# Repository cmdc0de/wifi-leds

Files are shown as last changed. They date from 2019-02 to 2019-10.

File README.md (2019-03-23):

# wifi-leds
wifi controlled LEDs

Goal of project:
* Build a web server on esp 32
* use a n-type mosfet to control power to an APA 102c LED strip
* use a ATECC608a for crypto and random number generator. you ask why? I say why not?
* add 2 displays 1. 2.4 SPI touch screen and 1 OLED I2C 
  * Again you ask why? mostly becuase I'm also working on the darknet 8 badge and one of these will be on that badge and it'll help me prepare.
* Pull out JTAG pins so I can try to debug from container.  Harder than it sounds becuase you need to run the open ocd server

Secondary Goals:
* Make the traces as thick as possible, so I can try to not only mill the board with my Bantam but also use 'print' the board using the Voltera.

Code:
* On linux:
* run buildESPContainer.sh
* ./runESPContainer.sh
* cd into firmware directory
* make menuconfig - set up usb port your usb to serial programmer is registered as
* make flash - build and push to dev board
* make monitor 
*

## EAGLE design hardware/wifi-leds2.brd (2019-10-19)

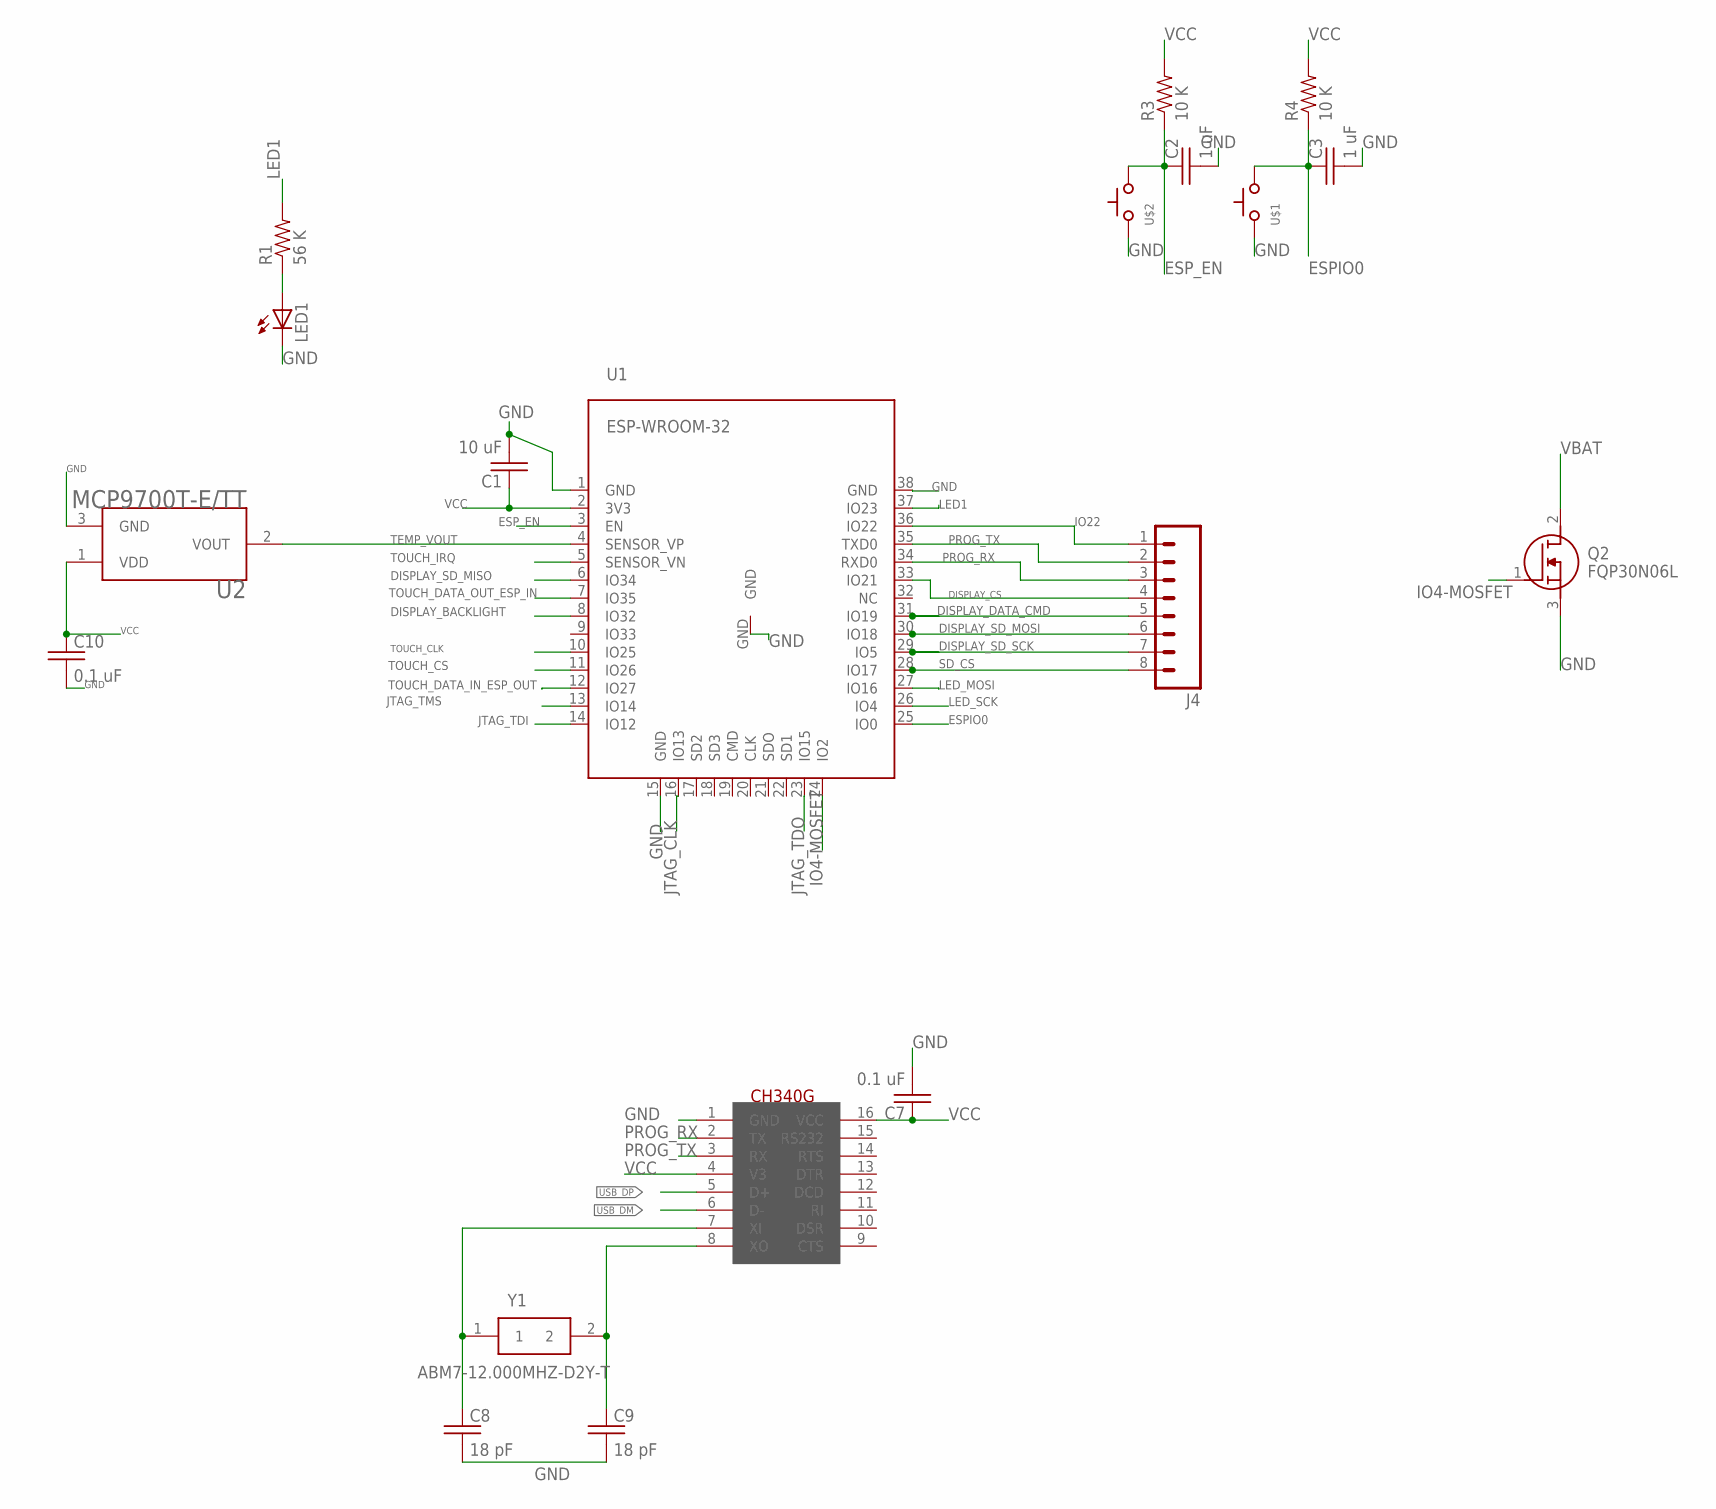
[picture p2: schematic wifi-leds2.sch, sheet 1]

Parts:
C1: 10 uF; C0805
C2, C3: 1 uF; C0805
C7, C10: 0.1 uF; C0805
C8, C9: 18 pF; C0805
J4: M08; 1X08_ROUND
LED1: LED3MM
Q2: FQP30N06L; TO254P470X1016X2019-3P
R1: 56 K; 0805
R3, R4: 10 K; 0805
U1: ESP-WROOM-32
U2: MCP9700T-E/TT; SOT95P237X112-3N
U$1, U$2: SWITCH_TACTILETACTILE-2PIN-NARROW; TACTILE-2PIN-NARROW
U$6: CH340G; SOIC16
Y1: ABM7-12.000MHZ-D2Y-T; ABM7

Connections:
DISPLAY_BACKLIGHT: U1.8 (IO32); also elsewhere on the board
DISPLAY_CS: J4.4, U1.33 (IO21); also elsewhere on the board
DISPLAY_DATA_CMD: J4.5, U1.31 (IO19); also elsewhere on the board
DISPLAY_SD_MISO: U1.6 (IO34); also elsewhere on the board
DISPLAY_SD_MOSI: J4.6, U1.30 (IO18); also elsewhere on the board
DISPLAY_SD_SCK: J4.7, U1.29 (IO5); also elsewhere on the board
ESPIO0: C3.1, R4.1, U1.25 (IO0), U$1.P$1 (A)
ESP_EN: C2.1, R3.1, U1.3 (EN), U$2.P$1 (A)
GND: C1.2, C2.2, C3.2, C7.2, C8.2, C9.2, C10.2, LED1.K (C), Q2.3 (S), U1.1 (GND), U1.15 (GND), U1.38 (GND), U1.GND, U2.3 (GND), U$1.P$2 (C), U$2.P$2 (C), U$6.1 (GND); also elsewhere on the board
IO4-MOSFET: Q2.1 (G), U1.24 (IO2)
IO22: J4.1, U1.36 (IO22)
JTAG_CLK: U1.16 (IO13); also elsewhere on the board
JTAG_TDI: U1.14 (IO12); also elsewhere on the board
JTAG_TDO: U1.23 (IO15); also elsewhere on the board
JTAG_TMS: U1.13 (IO14); also elsewhere on the board
LED1: R1.2, U1.37 (IO23)
LED_MOSI: U1.27 (IO16); also elsewhere on the board
LED_SCK: U1.26 (IO4); also elsewhere on the board
unnamed: LED1.A, R1.1
unnamed: C8.1, U$6.7 (XI), Y1.1
unnamed: C9.1, U$6.8 (XO), Y1.2
PROG_RX: J4.3, U1.34 (RXD0), U$6.2 (TX); also elsewhere on the board
PROG_TX: J4.2, U1.35 (TXD0), U$6.3 (RX); also elsewhere on the board
SD_CS: J4.8, U1.28 (IO17); also elsewhere on the board
TEMP_VOUT: U1.4 (SENSOR_VP), U2.2 (VOUT)
TOUCH_CLK: U1.10 (IO25); also elsewhere on the board
TOUCH_CS: U1.11 (IO26); also elsewhere on the board
TOUCH_DATA_IN_ESP_OUT: U1.12 (IO27); also elsewhere on the board
TOUCH_DATA_OUT_ESP_IN: U1.7 (IO35); also elsewhere on the board
TOUCH_IRQ: U1.5 (SENSOR_VN); also elsewhere on the board
USB_DM: U$6.6 (D-); also elsewhere on the board
USB_DP: U$6.5 (D+); also elsewhere on the board
VBAT: Q2.2 (D); also elsewhere on the board
VCC: C1.1, C7.1, C10.1, R3.2, R4.2, U1.2 (3V3), U2.1 (VDD), U$6.4 (V3), U$6.16 (VCC); also elsewhere on the board

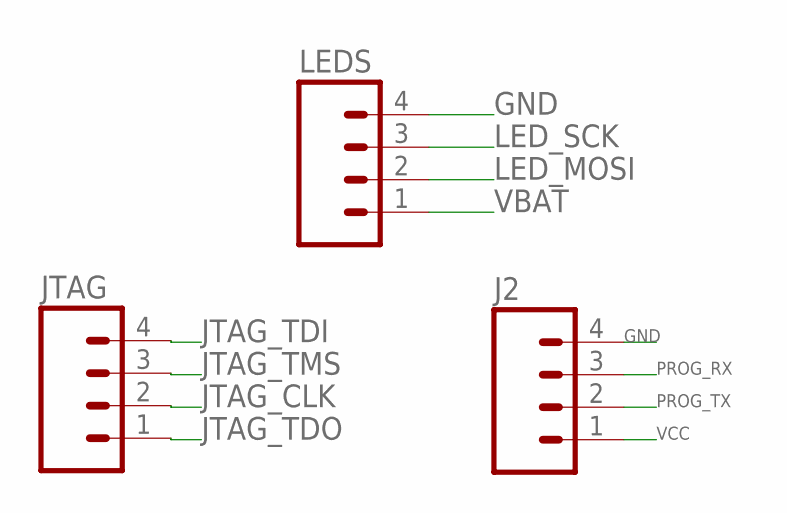
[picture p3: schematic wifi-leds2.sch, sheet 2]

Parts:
J2: M04PTH; 1X04
JTAG: M04PTH; 1X04
LEDS: M04POLAR; MOLEX-1X4

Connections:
GND: J2.4, LEDS.4; also elsewhere on the board
JTAG_CLK: JTAG.2; also elsewhere on the board
JTAG_TDI: JTAG.4; also elsewhere on the board
JTAG_TDO: JTAG.1; also elsewhere on the board
JTAG_TMS: JTAG.3; also elsewhere on the board
LED_MOSI: LEDS.2; also elsewhere on the board
LED_SCK: LEDS.3; also elsewhere on the board
PROG_RX: J2.3; also elsewhere on the board
PROG_TX: J2.2; also elsewhere on the board
VBAT: LEDS.1; also elsewhere on the board
VCC: J2.1; also elsewhere on the board

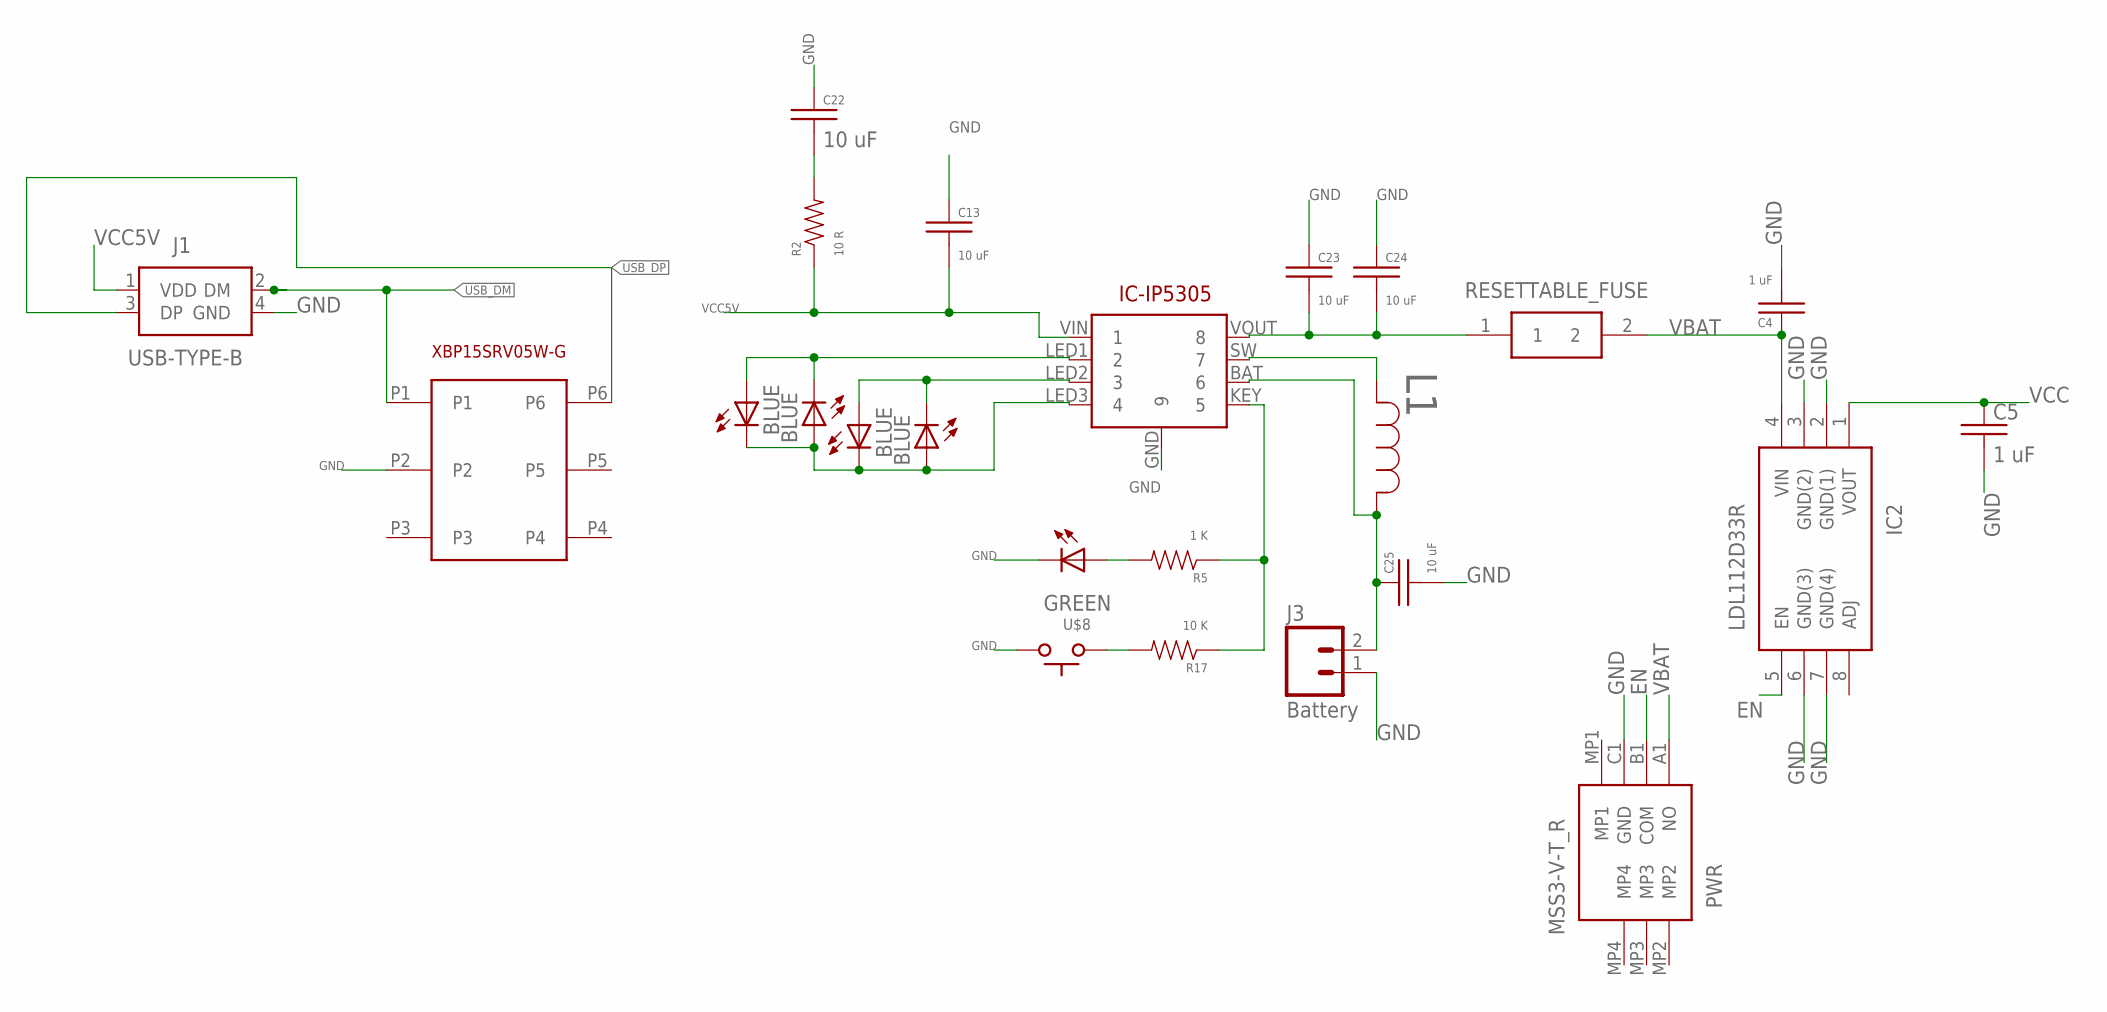
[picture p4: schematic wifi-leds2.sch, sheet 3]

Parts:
C4, C5: 1 uF; C0805
C13, C22, C23, C24, C25: 10 uF; C0805
CL1, CL2, CL3, CL4: BLUE; LED-1206
IC2: LDL112D33R; SOIC127P600X175-8N
IC-IP5305: IP5305ESOP8; SOIC127P600X165-8
J1: USB-TYPE-B; 61400413321
J3: Battery; JST-2-PTH
KEYLED: GREEN; LED-1206
L1: 2.2uH; IND_TAIYO_NRS4018
PWR: MSS3-V-T_R; MSS3VTR
R2: 10 R; 0805
R5: 1 K; 0805
R17: 10 K; 0805
RESETTABLE_FUSE: 0ZCJ0050FF2G; FUSC3216X55N
U$8: SWITCH_TACTILETACTILE-2PIN-NARROW; TACTILE-2PIN-NARROW
U$9: XBP15SRV05W-G; SOT-26P-XBP15SRV05W-G

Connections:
EN: IC2.5 (EN), PWR.B1 (COM)
GND: C4.2, C5.2, C13.1, C22.1, C23.1, C24.1, C25.2, IC2.2 (GND(1)), IC2.3 (GND(2)), IC2.6 (GND(3)), IC2.7 (GND(4)), IC-IP5305.GND (9), J1.4 (GND), J3.1, KEYLED.C, PWR.C1 (GND), U$8.P$1 (A), U$9.P2; also elsewhere on the board
unnamed: CL1.A, CL2.C, IC-IP5305.LED1 (2)
unnamed: CL3.A, CL4.C, IC-IP5305.LED2 (3)
unnamed: CL1.C, CL2.A, CL3.C, CL4.A, IC-IP5305.LED3 (4)
unnamed: C22.2, R2.2
unnamed: IC-IP5305.SW (7), L1.2
unnamed: C25.1, IC-IP5305.BAT (6), J3.2, L1.1
unnamed: IC-IP5305.KEY (5), R5.1, R17.1
unnamed: KEYLED.A, R5.2
unnamed: R17.2, U$8.P$2 (C)
unnamed: C23.2, C24.2, IC-IP5305.VOUT (8), RESETTABLE_FUSE.1
USB_DM: J1.2 (DM), U$9.P1; also elsewhere on the board
USB_DP: J1.3 (DP), U$9.P6; also elsewhere on the board
VBAT: C4.1, IC2.4 (VIN), PWR.A1 (NO), RESETTABLE_FUSE.2; also elsewhere on the board
VCC: C5.1, IC2.1 (VOUT); also elsewhere on the board
VCC5V: C13.2, IC-IP5305.VIN (1), J1.1 (VDD), R2.1

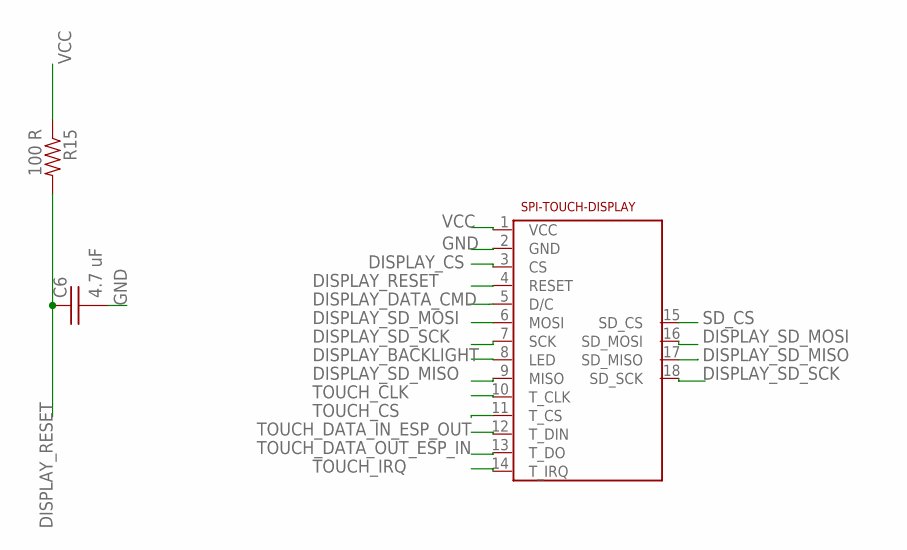
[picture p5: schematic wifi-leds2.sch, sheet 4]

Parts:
C6: 4.7 uF; C0805
R15: 100 R; 0805
U$3: 2.4-SPI-TFT-TOUCH-SSD-MODULE

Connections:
DISPLAY_BACKLIGHT: U$3.8 (LED); also elsewhere on the board
DISPLAY_CS: U$3.3 (CS); also elsewhere on the board
DISPLAY_DATA_CMD: U$3.5 (D/C); also elsewhere on the board
DISPLAY_RESET: C6.1, R15.2, U$3.4 (RESET)
DISPLAY_SD_MISO: U$3.9 (MISO), U$3.17 (SD_MISO); also elsewhere on the board
DISPLAY_SD_MOSI: U$3.6 (MOSI), U$3.16 (SD_MOSI); also elsewhere on the board
DISPLAY_SD_SCK: U$3.7 (SCK), U$3.18 (SD_SCK); also elsewhere on the board
GND: C6.2, U$3.2 (GND); also elsewhere on the board
SD_CS: U$3.15 (SD_CS); also elsewhere on the board
TOUCH_CLK: U$3.10 (T_CLK); also elsewhere on the board
TOUCH_CS: U$3.11 (T_CS); also elsewhere on the board
TOUCH_DATA_IN_ESP_OUT: U$3.12 (T_DIN); also elsewhere on the board
TOUCH_DATA_OUT_ESP_IN: U$3.13 (T_DO); also elsewhere on the board
TOUCH_IRQ: U$3.14 (T_IRQ); also elsewhere on the board
VCC: R15.1, U$3.1 (VCC); also elsewhere on the board

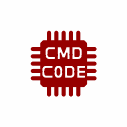
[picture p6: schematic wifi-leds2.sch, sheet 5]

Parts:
U$5: CMD_C0DE_LOGOCMD_CODE_LOGO_TOP_COPPER; CMD_C0DE_LOGO_TOP_COPPER

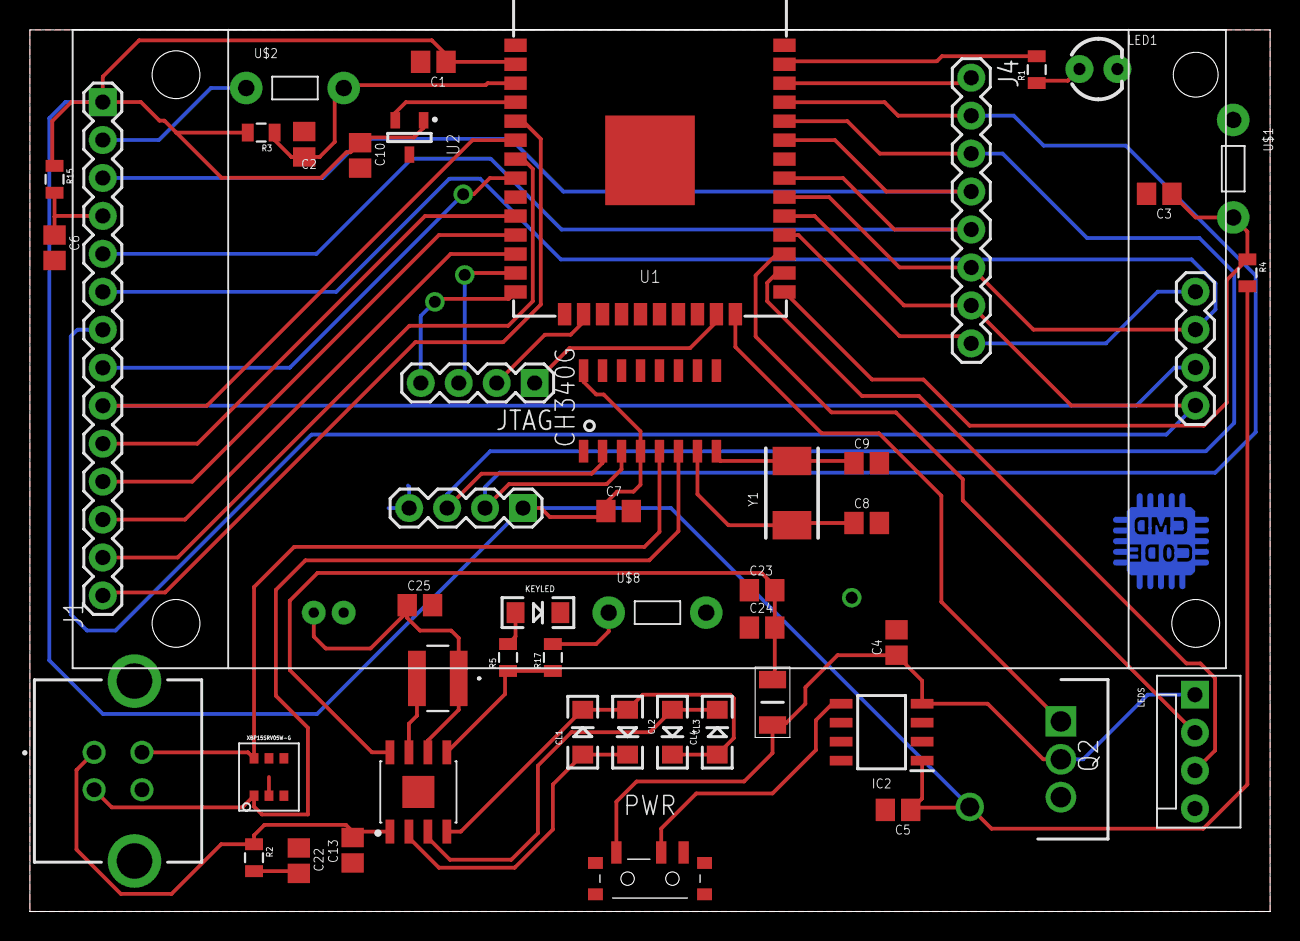
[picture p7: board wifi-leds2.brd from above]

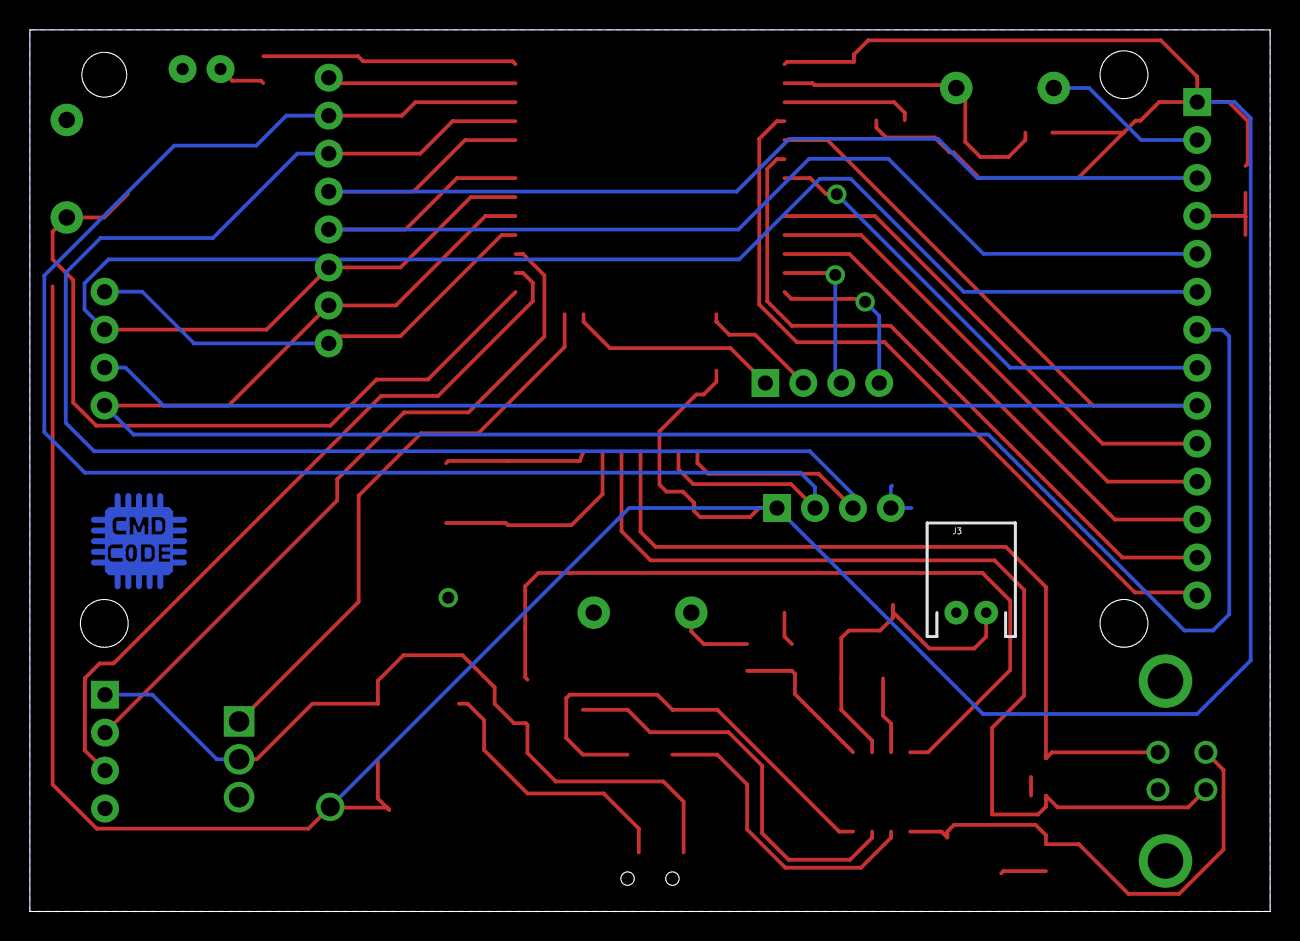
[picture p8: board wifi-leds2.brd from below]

Board: 2 copper layers, 83.0 x 59.0 mm, 50 parts (2 on the bottom side), 47 nets.

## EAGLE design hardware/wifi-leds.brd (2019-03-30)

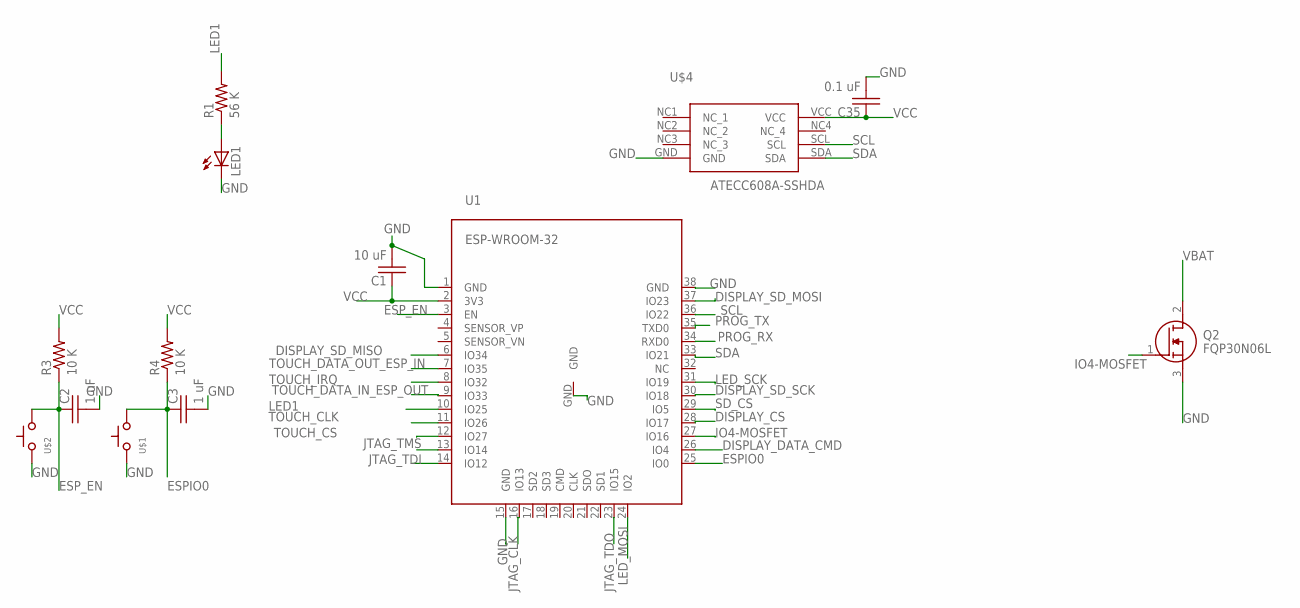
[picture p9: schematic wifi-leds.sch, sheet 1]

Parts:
C1: 10 uF; C0805
C2, C3: 1 uF; C0805
C35: 0.1 uF; C0805
LED1: LED3MM
Q2: FQP30N06L; TO254P470X1016X2019-3P
R1: 56 K; 0805
R3, R4: 10 K; 0805
U1: ESP-WROOM-32
U$1, U$2: SWITCH_TACTILETACTILE-2PIN-NARROW; TACTILE-2PIN-NARROW
U$4: ATECC608A-SSHDA; 8-SOIC

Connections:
DISPLAY_CS: U1.28 (IO17); also elsewhere on the board
DISPLAY_DATA_CMD: U1.26 (IO4); also elsewhere on the board
DISPLAY_SD_MISO: U1.6 (IO34); also elsewhere on the board
DISPLAY_SD_MOSI: U1.37 (IO23); also elsewhere on the board
DISPLAY_SD_SCK: U1.30 (IO18); also elsewhere on the board
ESPIO0: C3.1, R4.1, U1.25 (IO0), U$1.P$1 (A)
ESP_EN: C2.1, R3.1, U1.3 (EN), U$2.P$1 (A)
GND: C1.2, C2.2, C3.2, C35.2, LED1.K (C), Q2.3 (S), U1.1 (GND), U1.15 (GND), U1.38 (GND), U1.GND, U$1.P$2 (C), U$2.P$2 (C), U$4.GND; also elsewhere on the board
IO4-MOSFET: Q2.1 (G), U1.27 (IO16)
JTAG_CLK: U1.16 (IO13); also elsewhere on the board
JTAG_TDI: U1.14 (IO12); also elsewhere on the board
JTAG_TDO: U1.23 (IO15); also elsewhere on the board
JTAG_TMS: U1.13 (IO14); also elsewhere on the board
LED1: R1.2, U1.10 (IO25)
LED_MOSI: U1.24 (IO2); also elsewhere on the board
LED_SCK: U1.31 (IO19); also elsewhere on the board
unnamed: LED1.A, R1.1
PROG_RX: U1.34 (RXD0); also elsewhere on the board
PROG_TX: U1.35 (TXD0); also elsewhere on the board
SCL: U1.36 (IO22), U$4.SCL; also elsewhere on the board
SDA: U1.33 (IO21), U$4.SDA; also elsewhere on the board
SD_CS: U1.29 (IO5); also elsewhere on the board
TOUCH_CLK: U1.11 (IO26); also elsewhere on the board
TOUCH_CS: U1.12 (IO27); also elsewhere on the board
TOUCH_DATA_IN_ESP_OUT: U1.9 (IO33); also elsewhere on the board
TOUCH_DATA_OUT_ESP_IN: U1.7 (IO35); also elsewhere on the board
TOUCH_IRQ: U1.8 (IO32); also elsewhere on the board
VBAT: Q2.2 (D); also elsewhere on the board
VCC: C1.1, C35.1, R3.2, R4.2, U1.2 (3V3), U$4.VCC; also elsewhere on the board

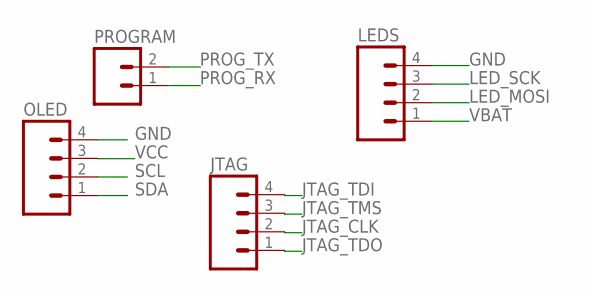
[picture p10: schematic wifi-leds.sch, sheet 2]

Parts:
JTAG: M04PTH; 1X04
LEDS: M04POLAR; MOLEX-1X4
OLED: M04PTH; 1X04
PROGRAM: M02PTH; 1X02

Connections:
GND: LEDS.4, OLED.4; also elsewhere on the board
JTAG_CLK: JTAG.2; also elsewhere on the board
JTAG_TDI: JTAG.4; also elsewhere on the board
JTAG_TDO: JTAG.1; also elsewhere on the board
JTAG_TMS: JTAG.3; also elsewhere on the board
LED_MOSI: LEDS.2; also elsewhere on the board
LED_SCK: LEDS.3; also elsewhere on the board
PROG_RX: PROGRAM.1; also elsewhere on the board
PROG_TX: PROGRAM.2; also elsewhere on the board
SCL: OLED.2; also elsewhere on the board
SDA: OLED.1; also elsewhere on the board
VBAT: LEDS.1; also elsewhere on the board
VCC: OLED.3; also elsewhere on the board

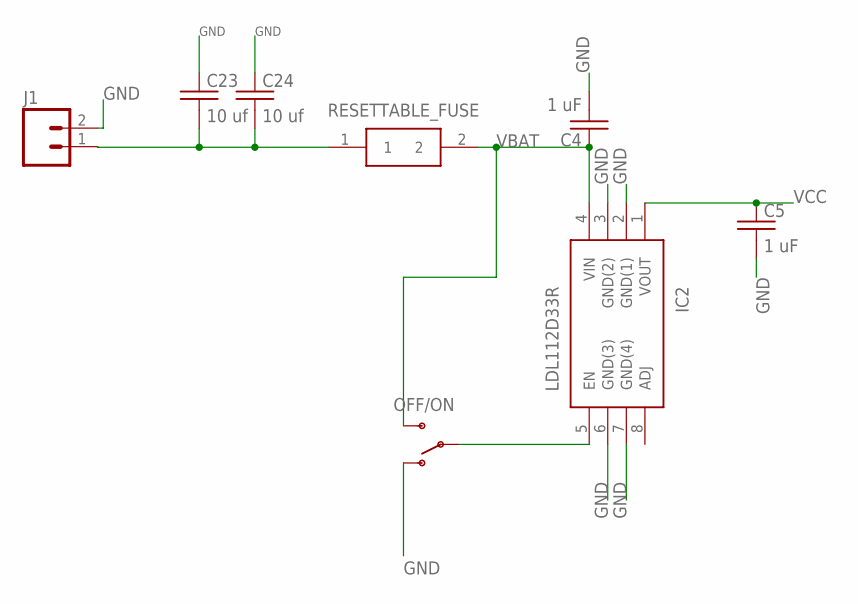
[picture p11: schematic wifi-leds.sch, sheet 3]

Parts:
C4, C5: 1 uF; C0805
C23, C24: 10 uf; C0805
IC2: LDL112D33R; SOIC127P600X175-8N
J1: M02PTH; 1X02
OFF/ON: SWITCH-SPSTKIT; SWITCH-SPDT_KIT
RESETTABLE_FUSE: 0ZCJ0050FF2G; FUSC3216X55N

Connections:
GND: C4.2, C5.2, C23.1, C24.1, IC2.2 (GND(1)), IC2.3 (GND(2)), IC2.6 (GND(3)), IC2.7 (GND(4)), J1.2, OFF/ON.1 (O); also elsewhere on the board
unnamed: IC2.5 (EN), OFF/ON.2
unnamed: C23.2, C24.2, J1.1, RESETTABLE_FUSE.1
VBAT: C4.1, IC2.4 (VIN), OFF/ON.3 (S), RESETTABLE_FUSE.2; also elsewhere on the board
VCC: C5.1, IC2.1 (VOUT); also elsewhere on the board

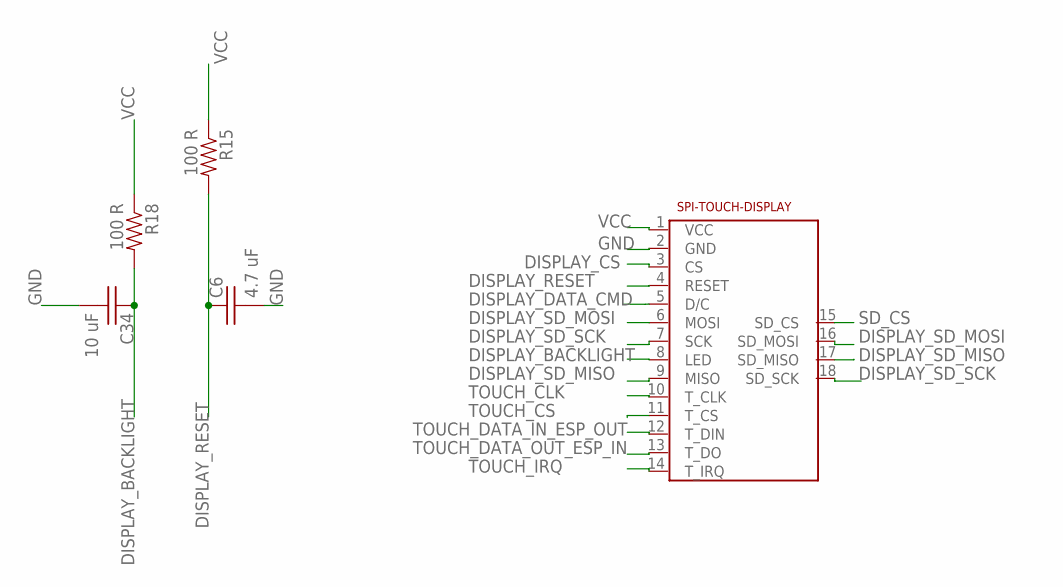
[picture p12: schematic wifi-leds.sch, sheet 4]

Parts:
C6: 4.7 uF; C0805
C34: 10 uF; C0805
R15, R18: 100 R; 0805
U$3: 2.4-SPI-TFT-TOUCH-SSD-MODULE

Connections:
DISPLAY_BACKLIGHT: C34.1, R18.2, U$3.8 (LED)
DISPLAY_CS: U$3.3 (CS); also elsewhere on the board
DISPLAY_DATA_CMD: U$3.5 (D/C); also elsewhere on the board
DISPLAY_RESET: C6.1, R15.2, U$3.4 (RESET)
DISPLAY_SD_MISO: U$3.9 (MISO), U$3.17 (SD_MISO); also elsewhere on the board
DISPLAY_SD_MOSI: U$3.6 (MOSI), U$3.16 (SD_MOSI); also elsewhere on the board
DISPLAY_SD_SCK: U$3.7 (SCK), U$3.18 (SD_SCK); also elsewhere on the board
GND: C6.2, C34.2, U$3.2 (GND); also elsewhere on the board
SD_CS: U$3.15 (SD_CS); also elsewhere on the board
TOUCH_CLK: U$3.10 (T_CLK); also elsewhere on the board
TOUCH_CS: U$3.11 (T_CS); also elsewhere on the board
TOUCH_DATA_IN_ESP_OUT: U$3.12 (T_DIN); also elsewhere on the board
TOUCH_DATA_OUT_ESP_IN: U$3.13 (T_DO); also elsewhere on the board
TOUCH_IRQ: U$3.14 (T_IRQ); also elsewhere on the board
VCC: R15.1, R18.1, U$3.1 (VCC); also elsewhere on the board


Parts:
U$5: CMD_C0DE_LOGOCMD_CODE_LOGO_TOP_COPPER; CMD_C0DE_LOGO_TOP_COPPER

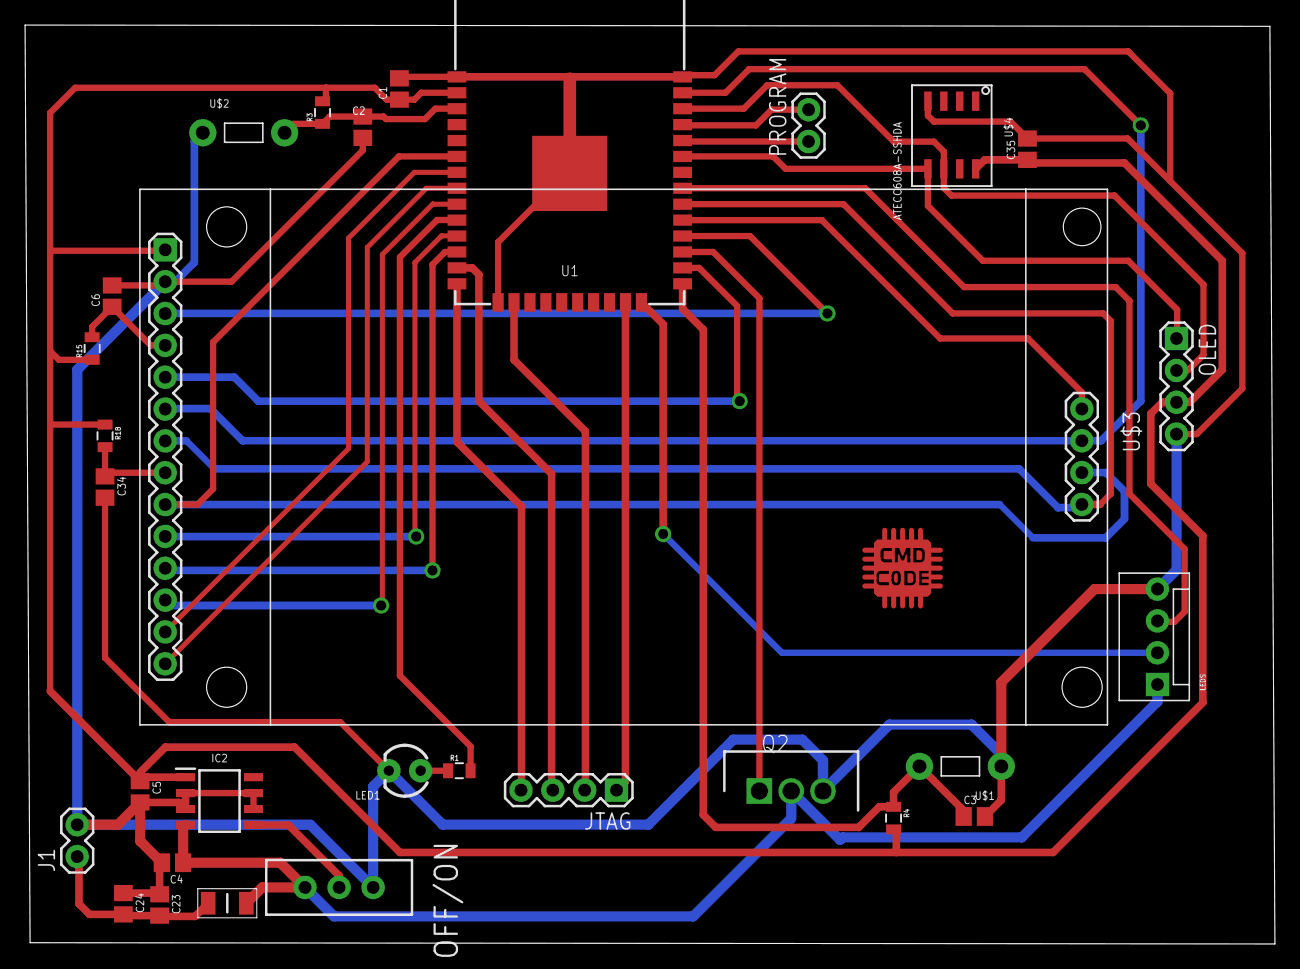
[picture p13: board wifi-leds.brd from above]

Board: 2 copper layers, 99.7 x 73.3 mm, 31 parts (0 on the bottom side), 33 nets.

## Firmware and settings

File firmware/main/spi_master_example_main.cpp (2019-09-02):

/* SPI Master example

   This example code is in the Public Domain (or CC0 licensed, at your option.)

   Unless required by applicable law or agreed to in writing, this
   software is distributed on an "AS IS" BASIS, WITHOUT WARRANTIES OR
   CONDITIONS OF ANY KIND, either express or implied.
*/
#include <stdio.h>
#include <stdlib.h>
#include <string.h>
#include "freertos/FreeRTOS.h"
#include "freertos/task.h"
#include "esp_system.h"
#include "driver/spi_master.h"
#include "soc/gpio_struct.h"
#include "driver/gpio.h"

#include "pretty_effect.h"
#include <libesp/system.h>
#include <libesp/i2c.hpp>
#include <esp_log.h>

/*
 This code displays some fancy graphics on the 320x240 LCD on an ESP-WROVER_KIT board.
 This example demonstrates the use of both spi_device_transmit as well as
 spi_device_queue_trans/spi_device_get_trans_result and pre-transmit callbacks.

 Some info about the ILI9341/ST7789V: It has an C/D line, which is connected to a GPIO here. It expects this
 line to be low for a command and high for data. We use a pre-transmit callback here to control that
 line: every transaction has as the user-definable argument the needed state of the D/C line and just
 before the transaction is sent, the callback will set this line to the correct state.
*/

#define PIN_NUM_MISO 19 //25
#define PIN_NUM_MOSI 23
#define PIN_NUM_CLK  18 //19
#define PIN_NUM_CS   17 //22

#define PIN_NUM_DC   4 //21
#define PIN_NUM_RST  -1 //18
#define PIN_NUM_BCKL -1 //5


#define LED_PIN_MOSI 16 //13
#define LED_PIN_CLK  2 //14
#define LED_PIN_NONE -1
//To speed up transfers, every SPI transfer sends a bunch of lines. This define specifies how many. More means more memory use,
//but less overhead for setting up / finishing transfers. Make sure 240 is dividable by this.
#define PARALLEL_LINES 16

extern "C" {
	void app_main();

}

/*
 The LCD needs a bunch of command/argument values to be initialized. They are stored in this struct.
*/
typedef struct {
    uint8_t cmd;
    uint8_t data[16];
    uint8_t databytes; //No of data in data; bit 7 = delay after set; 0xFF = end of cmds.
} lcd_init_cmd_t;

typedef enum {
    LCD_TYPE_ILI = 1,
    LCD_TYPE_ST,
    LCD_TYPE_MAX,
} type_lcd_t;

//Place data into DRAM. Constant data gets placed into DROM by default, which is not accessible by DMA.
DRAM_ATTR static const lcd_init_cmd_t st_init_cmds[]={
    /* Memory Data Access Control, MX=MV=1, MY=ML=MH=0, RGB=0 */
    {0x36, {(1<<5)|(1<<6)}, 1},
    /* Interface Pixel Format, 16bits/pixel for RGB/MCU interface */
    {0x3A, {0x55}, 1},
    /* Porch Setting */
    {0xB2, {0x0c, 0x0c, 0x00, 0x33, 0x33}, 5},
    /* Gate Control, Vgh=13.65V, Vgl=-10.43V */
    {0xB7, {0x45}, 1},
    /* VCOM Setting, VCOM=1.175V */
    {0xBB, {0x2B}, 1},
    /* LCM Control, XOR: RGB, MX, MH */
    {0xC0, {0x2C}, 1},
    /* VDV and VRH Command Enable, enable=1 */
    {0xC2, {0x01, 0xff}, 2},
    /* VRH Set, Vap=4.4+... */
    {0xC3, {0x11}, 1},
    /* VDV Set, VDV=0 */
    {0xC4, {0x20}, 1},
    /* Frame Rate Control, 60Hz, inversion=0 */
    {0xC6, {0x0f}, 1},
    /* Power Control 1, AVDD=6.8V, AVCL=-4.8V, VDDS=2.3V */
    {0xD0, {0xA4, 0xA1}, 1},
    /* Positive Voltage Gamma Control */
    {0xE0, {0xD0, 0x00, 0x05, 0x0E, 0x15, 0x0D, 0x37, 0x43, 0x47, 0x09, 0x15, 0x12, 0x16, 0x19}, 14},
    /* Negative Voltage Gamma Control */
    {0xE1, {0xD0, 0x00, 0x05, 0x0D, 0x0C, 0x06, 0x2D, 0x44, 0x40, 0x0E, 0x1C, 0x18, 0x16, 0x19}, 14},
    /* Sleep Out */
    {0x11, {0}, 0x80},
    /* Display On */
    {0x29, {0}, 0x80},
    {0, {0}, 0xff}
};

DRAM_ATTR static const lcd_init_cmd_t ili_init_cmds[]={
    /* Power contorl B, power control = 0, DC_ENA = 1 */
    {0xCF, {0x00, 0x83, 0X30}, 3},
    /* Power on sequence control,
     * cp1 keeps 1 frame, 1st frame enable
     * vcl = 0, ddvdh=3, vgh=1, vgl=2
     * DDVDH_ENH=1
     */
    {0xED, {0x64, 0x03, 0X12, 0X81}, 4},
    /* Driver timing control A,
     * non-overlap=default +1
     * EQ=default - 1, CR=default
     * pre-charge=default - 1
     */
    {0xE8, {0x85, 0x01, 0x79}, 3},
    /* Power control A, Vcore=1.6V, DDVDH=5.6V */
    {0xCB, {0x39, 0x2C, 0x00, 0x34, 0x02}, 5},
    /* Pump ratio control, DDVDH=2xVCl */
    {0xF7, {0x20}, 1},
    /* Driver timing control, all=0 unit */
    {0xEA, {0x00, 0x00}, 2},
    /* Power control 1, GVDD=4.75V */
    {0xC0, {0x26}, 1},
    /* Power control 2, DDVDH=VCl*2, VGH=VCl*7, VGL=-VCl*3 */
    {0xC1, {0x11}, 1},
    /* VCOM control 1, VCOMH=4.025V, VCOML=-0.950V */
    {0xC5, {0x35, 0x3E}, 2},
    /* VCOM control 2, VCOMH=VMH-2, VCOML=VML-2 */
    {0xC7, {0xBE}, 1},
    /* Memory access contorl, MX=MY=0, MV=1, ML=0, RGB=1, MH=0 */
    {0x36, {0x28}, 1},
    /* Pixel format, 16bits/pixel for RGB/MCU interface */
    {0x3A, {0x55}, 1},
    /* Frame rate control, f=fosc, 70Hz fps */
    {0xB1, {0x00, 0x1B}, 2},
    /* Enable 3G, disabled */
    {0xF2, {0x08}, 1},
    /* Gamma set, curve 1 */
    {0x26, {0x01}, 1},
    /* Positive gamma correction */
    {0xE0, {0x1F, 0x1A, 0x18, 0x0A, 0x0F, 0x06, 0x45, 0X87, 0x32, 0x0A, 0x07, 0x02, 0x07, 0x05, 0x00}, 15},
    /* Negative gamma correction */
    {0XE1, {0x00, 0x25, 0x27, 0x05, 0x10, 0x09, 0x3A, 0x78, 0x4D, 0x05, 0x18, 0x0D, 0x38, 0x3A, 0x1F}, 15},
    /* Column address set, SC=0, EC=0xEF */
    {0x2A, {0x00, 0x00, 0x00, 0xEF}, 4},
    /* Page address set, SP=0, EP=0x013F */
    {0x2B, {0x00, 0x00, 0x01, 0x3f}, 4},
    /* Memory write */
    {0x2C, {0}, 0},
    /* Entry mode set, Low vol detect disabled, normal display */
    {0xB7, {0x07}, 1},
    /* Display function control */
    {0xB6, {0x0A, 0x82, 0x27, 0x00}, 4},
    /* Sleep out */
    {0x11, {0}, 0x80},
    /* Display on */
    {0x29, {0}, 0x80},
    {0, {0}, 0xff},
};

//Send a command to the LCD. Uses spi_device_transmit, which waits until the transfer is complete.
void lcd_cmd(spi_device_handle_t spi, const uint8_t cmd)
{
    esp_err_t ret;
    spi_transaction_t t;
    memset(&t, 0, sizeof(t));       //Zero out the transaction
    t.length=8;                     //Command is 8 bits
    t.tx_buffer=&cmd;               //The data is the cmd itself
    t.user=(void*)0;                //D/C needs to be set to 0
    ret=spi_device_transmit(spi, &t);  //Transmit!
    assert(ret==ESP_OK);            //Should have had no issues.
}

//Send data to the LCD. Uses spi_device_transmit, which waits until the transfer is complete.
void lcd_data(spi_device_handle_t spi, const uint8_t *data, int len)
{
    esp_err_t ret;
    spi_transaction_t t;
    if (len==0) return;             //no need to send anything
    memset(&t, 0, sizeof(t));       //Zero out the transaction
    t.length=len*8;                 //Len is in bytes, transaction length is in bits.
    t.tx_buffer=data;               //Data
    t.user=(void*)1;                //D/C needs to be set to 1
    ret=spi_device_transmit(spi, &t);  //Transmit!
    assert(ret==ESP_OK);            //Should have had no issues.
}

//This function is called (in irq context!) just before a transmission starts. It will
//set the D/C line to the value indicated in the user field.
void lcd_spi_pre_transfer_callback(spi_transaction_t *t)
{
    int dc=(int)t->user;
    gpio_set_level((gpio_num_t)PIN_NUM_DC, dc);
}

uint32_t lcd_get_id(spi_device_handle_t spi)
{
    //get_id cmd
    lcd_cmd( spi, 0x04);

    spi_transaction_t t;
    memset(&t, 0, sizeof(t));
    t.length=8*3;
    t.flags = SPI_TRANS_USE_RXDATA;
    t.user = (void*)1;

    esp_err_t ret = spi_device_transmit(spi, &t);
    assert( ret == ESP_OK );

    return *(uint32_t*)t.rx_data;
}

//Initialize the display
void lcd_init(spi_device_handle_t spi)
{
    int cmd=0;
    const lcd_init_cmd_t* lcd_init_cmds;

    //Initialize non-SPI GPIOs
    gpio_set_direction((gpio_num_t)PIN_NUM_DC, GPIO_MODE_OUTPUT);
    //gpio_set_direction((gpio_num_t)PIN_NUM_RST, GPIO_MODE_OUTPUT);
    //gpio_set_direction((gpio_num_t)PIN_NUM_BCKL, GPIO_MODE_OUTPUT);

    //Reset the display
    //gpio_set_level((gpio_num_t)PIN_NUM_RST, 0);
    //vTaskDelay(100 / portTICK_RATE_MS);
    //gpio_set_level((gpio_num_t)PIN_NUM_RST, 1);
    //vTaskDelay(100 / portTICK_RATE_MS);

    //detect LCD type
    uint32_t lcd_id = lcd_get_id(spi);
    int lcd_detected_type = 0;
    int lcd_type;

    printf("LCD ID: %08X\n", lcd_id);
    if ( lcd_id == 0 ) {
        //zero, ili
        lcd_detected_type = LCD_TYPE_ILI;
        printf("ILI9341 detected.\n");
    } else {
        // none-zero, ST
        lcd_detected_type = LCD_TYPE_ST;
        printf("ST7789V detected.\n");
    }

#ifdef CONFIG_LCD_TYPE_AUTO
    lcd_type = lcd_detected_type;
#elif defined( CONFIG_LCD_TYPE_ST7789V )
    printf("kconfig: force CONFIG_LCD_TYPE_ST7789V.\n");
    lcd_type = LCD_TYPE_ST;
#elif defined( CONFIG_LCD_TYPE_ILI9341 )
    printf("kconfig: force CONFIG_LCD_TYPE_ILI9341.\n");
    lcd_type = LCD_TYPE_ILI;
#endif
    if ( lcd_type == LCD_TYPE_ST ) {
        printf("LCD ST7789V initialization.\n");
        lcd_init_cmds = st_init_cmds;
    } else {
        printf("LCD ILI9341 initialization.\n");
        lcd_init_cmds = ili_init_cmds;
    }

    //Send all the commands
    while (lcd_init_cmds[cmd].databytes!=0xff) {
        lcd_cmd(spi, lcd_init_cmds[cmd].cmd);
        lcd_data(spi, lcd_init_cmds[cmd].data, lcd_init_cmds[cmd].databytes&0x1F);
        if (lcd_init_cmds[cmd].databytes&0x80) {
            vTaskDelay(100 / portTICK_RATE_MS);
        }
        cmd++;
    }

    ///Enable backlight
    //gpio_set_level((gpio_num_t)PIN_NUM_BCKL, 0);
}


//To send a set of lines we have to send a command, 2 data bytes, another command, 2 more data bytes and another command
//before sending the line data itself; a total of 6 transactions. (We can't put all of this in just one transaction
//because the D/C line needs to be toggled in the middle.)
//This routine queues these commands up so they get sent as quickly as possible.
static void send_lines(spi_device_handle_t spi, int ypos, uint16_t *linedata)
{
    esp_err_t ret;
    int x;
    //Transaction descriptors. Declared static so they're not allocated on the stack; we need this memory even when this
    //function is finished because the SPI driver needs access to it even while we're already calculating the next line.
    static spi_transaction_t trans[6];

    //In theory, it's better to initialize trans and data only once and hang on to the initialized
    //variables. We allocate them on the stack, so we need to re-init them each call.
    for (x=0; x<6; x++) {
        memset(&trans[x], 0, sizeof(spi_transaction_t));
        if ((x&1)==0) {
            //Even transfers are commands
            trans[x].length=8;
            trans[x].user=(void*)0;
        } else {
            //Odd transfers are data
            trans[x].length=8*4;
            trans[x].user=(void*)1;
        }
        trans[x].flags=SPI_TRANS_USE_TXDATA;
    }
    trans[0].tx_data[0]=0x2A;           //Column Address Set
    trans[1].tx_data[0]=0;              //Start Col High
    trans[1].tx_data[1]=0;              //Start Col Low
    trans[1].tx_data[2]=(320)>>8;       //End Col High
    trans[1].tx_data[3]=(320)&0xff;     //End Col Low
    trans[2].tx_data[0]=0x2B;           //Page address set
    trans[3].tx_data[0]=ypos>>8;        //Start page high
    trans[3].tx_data[1]=ypos&0xff;      //start page low
    trans[3].tx_data[2]=(ypos+PARALLEL_LINES)>>8;    //end page high
    trans[3].tx_data[3]=(ypos+PARALLEL_LINES)&0xff;  //end page low
    trans[4].tx_data[0]=0x2C;           //memory write
    trans[5].tx_buffer=linedata;        //finally send the line data
    trans[5].length=320*2*8*PARALLEL_LINES;          //Data length, in bits
    trans[5].flags=0; //undo SPI_TRANS_USE_TXDATA flag

    //Queue all transactions.
    for (x=0; x<6; x++) {
        ret=spi_device_queue_trans(spi, &trans[x], portMAX_DELAY);
        assert(ret==ESP_OK);
    }

    //When we are here, the SPI driver is busy (in the background) getting the transactions sent. That happens
    //mostly using DMA, so the CPU doesn't have much to do here. We're not going to wait for the transaction to
    //finish because we may as well spend the time calculating the next line. When that is done, we can call
    //send_line_finish, which will wait for the transfers to be done and check their status.
}


static void send_line_finish(spi_device_handle_t spi)
{
    spi_transaction_t *rtrans;
    esp_err_t ret;
    //Wait for all 6 transactions to be done and get back the results.
    for (int x=0; x<6; x++) {
        ret=spi_device_get_trans_result(spi, &rtrans, portMAX_DELAY);
        assert(ret==ESP_OK);
        //We could inspect rtrans now if we received any info back. The LCD is treated as write-only, though.
    }
}


//Simple routine to generate some patterns and send them to the LCD. Don't expect anything too
//impressive. Because the SPI driver handles transactions in the background, we can calculate the next line
//while the previous one is being sent.
static void display_pretty_colors(spi_device_handle_t spi)
{
    uint16_t *lines[2];
    //Allocate memory for the pixel buffers
    for (int i=0; i<2; i++) {
        lines[i]=(uint16_t*)heap_caps_malloc(320*PARALLEL_LINES*sizeof(uint16_t), MALLOC_CAP_DMA);
        assert(lines[i]!=NULL);
    }
    int frame=0;
    //Indexes of the line currently being sent to the LCD and the line we're calculating.
    int sending_line=-1;
    int calc_line=0;

    while(1) {
        frame++;
        for (int y=0; y<240; y+=PARALLEL_LINES) {
            //Calculate a line.
            pretty_effect_calc_lines(lines[calc_line], y, frame, PARALLEL_LINES);
            //Finish up the sending process of the previous line, if any
            if (sending_line!=-1) send_line_finish(spi);
            //Swap sending_line and calc_line
            sending_line=calc_line;
            calc_line=(calc_line==1)?0:1;
            //Send the line we currently calculated.
            send_lines(spi, y, lines[sending_line]);
            //The line set is queued up for sending now; the actual sending happens in the
            //background. We can go on to calculate the next line set as long as we do not
            //touch line[sending_line]; the SPI sending process is still reading from that.
        }
    }
}


//////////////////////////////////////////////
// LEDS

class ErrorType {
public:
	ErrorType(esp_err_t et) : ErrType(et) {}
	bool ok() {return ErrType==ESP_OK;}
	const char *toString() {return esp_err_to_name(ErrType);}
private:
	esp_err_t ErrType;
};

class Wiring {
public:
	Wiring(){}
	bool init() {
		return onInit();
	}
	ErrorType shutdown() {
		return onShutdown();
	}
	virtual ErrorType sendAndReceive(uint8_t out, uint8_t &in)=0;
	virtual ErrorType send(uint8_t *p, uint16_t len) =0;
	virtual ErrorType onShutdown()=0;
	virtual ~Wiring() {}
protected:
	virtual bool onInit()=0;
};

class ESP32SPIWiring : public Wiring {
public:
	static ESP32SPIWiring create(spi_host_device_t shd, int miso, int mosi, int clk, int cs, int tb, int dma) {
		ESP32SPIWiring esp32(shd,miso,mosi,clk,cs, tb,dma);
		return esp32;
	}
public:
	virtual ErrorType sendAndReceive(uint8_t out, uint8_t &in) {
    	spi_transaction_t t;
    	memset(&t, 0, sizeof(t));   //Zero out the transaction
    	t.length=8;                 //Len is in bytes, transaction length is in bits.
		t.tx_data[0]=out;             //Data
		t.flags = SPI_TRANS_USE_RXDATA | SPI_TRANS_USE_TXDATA;
		t.user=(void*)1;              
    		esp_err_t r = spi_device_transmit(spi, &t);  //Transmit!
		in = t.rx_data[0];
		return r;
	}
	virtual ErrorType send(uint8_t *p, uint16_t len) {
    		if (len==0) return ESP_OK;       //no need to send anything
    		spi_transaction_t t;
    		memset(&t, 0, sizeof(t));   //Zero out the transaction
    		t.length=len*8;                 //Len is in bytes, transaction length is in bits.
		t.tx_buffer=p;             //Data
		t.user=(void*)2;              
    		esp_err_t r = spi_device_transmit(spi, &t);  //Transmit!
		return r;
	}
	virtual ~ESP32SPIWiring() {
		shutdown();
	}
public:
	ErrorType onShutdown() {
		return spi_bus_free(SpiHD);
	}
protected:
	ESP32SPIWiring(spi_host_device_t spihd, int miso, int mosi, int clk, int cs, int bufSize, int dmachannel) 
		: SpiHD(spihd), PinMiso(miso), PinMosi(mosi), PinCLK(clk), PinCS(cs), TransferBufferSize(bufSize), 
		DMAChannel(dmachannel) { }
	virtual bool onInit() {
		esp_err_t ret;

		spi_bus_config_t buscfg;
		buscfg.miso_io_num=PinMiso;
		buscfg.mosi_io_num=PinMosi;
		buscfg.sclk_io_num=PinCLK;
		buscfg.quadwp_io_num=-1;
		buscfg.quadhd_io_num=-1;
		buscfg.max_transfer_sz=TransferBufferSize;
		buscfg.flags = SPICOMMON_BUSFLAG_MASTER;
		buscfg.intr_flags = 0;

		//Initialize the SPI bus
		ret=spi_bus_initialize(SpiHD, &buscfg, DMAChannel);
		ESP_ERROR_CHECK(ret);

		spi_device_interface_config_t devcfg;
		devcfg.clock_speed_hz=1*1000*1000;         //Clock out at 1 MHz
		devcfg.mode=0;                             //SPI mode 0
		devcfg.spics_io_num=PinCS;               	//CS pin
		devcfg.queue_size=3;                       //We want to be able to queue 3 transactions at a time
		devcfg.duty_cycle_pos = 0;
		devcfg.cs_ena_pretrans = 0;
		devcfg.cs_ena_posttrans = 0; 
		devcfg.input_delay_ns = 0;
		devcfg.flags = 0;
		devcfg.pre_cb = nullptr;
		devcfg.post_cb = nullptr;

		//Attach the LED to the SPI bus
		ret=spi_bus_add_device(SpiHD, &devcfg, &spi);
		ESP_ERROR_CHECK(ret);
	 	return ESP_OK==ret;
	}
private:
	spi_host_device_t SpiHD;
	int PinMiso;
	int PinMosi;
	int PinCLK;
	int PinCS;
	int TransferBufferSize;
	int DMAChannel;
	spi_device_handle_t spi;
};

/*
	Brightness is a percentage
*/
class RGB {
public:
	static const RGB WHITE;
	static const RGB BLUE;
	static const RGB GREEN;
	static const RGB RED;
public:
	RGB() : B(0), G(0), R(0), Brightness(100) {}
	RGB(uint8_t r, uint8_t g, uint8_t b, uint8_t brightness) : B(b), G(g), R(r), Brightness(brightness) {}
	RGB(const RGB &r) : B(r.B), G(r.G), R(r.R), Brightness(r.Brightness) {}
	uint8_t getBlue()  {return B;}
	uint8_t getRed()   {return R;}
	uint8_t getGreen() {return G;}
	uint8_t getBrightness() {return Brightness;}
	void setBlue(uint8_t v) 	{B=v;}
	void setRed(uint8_t v)  	{R=v;}
	void setGreen(uint8_t v) 	{G=v;}
	void setBrightness(uint8_t v)	{Brightness=((v>100)?100:v);}
private:
	uint8_t B;
	uint8_t G;
	uint8_t R;
	uint8_t Brightness;
} __attribute__((packed));;

const RGB RGB::WHITE(255,255,255,100);
const RGB RGB::BLUE(0,0,255,100);
const RGB RGB::GREEN(0,255,0,100);
const RGB RGB::RED(255,0,0,100);

class APA102c {
public:
	//0xE0 because high 3 bits are always on
	static const uint8_t BRIGHTNESS_START_BITS = 0xE0;
	static const uint8_t MAX_BRIGHTNESS			 = 31;
	static const char *LOG;
public:
	APA102c(Wiring *spiI) : SPIInterface(spiI), BufferSize(0), LedBuffer1(0) {}
	
	void init(uint16_t nleds, RGB *ledBuf) {
		delete [] LedBuffer1;
		BufferSize = (nleds*4)+8;
		LedBuffer1 = new char [BufferSize];
		int bufOff = 0;
		LedBuffer1[bufOff]   = 0x0;
		LedBuffer1[++bufOff] = 0x0;
		LedBuffer1[++bufOff] = 0x0;
		LedBuffer1[++bufOff] = 0x0;
		for(int l=0;l<nleds;++l) {
			uint8_t bright = ledBuf[l].getBrightness();
			bright = (uint8_t)(((float)bright/100.0f)*MAX_BRIGHTNESS);
			LedBuffer1[++bufOff] = BRIGHTNESS_START_BITS|bright;
			LedBuffer1[++bufOff] = ledBuf[l].getBlue();
			LedBuffer1[++bufOff] = ledBuf[l].getGreen();
			LedBuffer1[++bufOff] = ledBuf[l].getRed();
		}
		LedBuffer1[++bufOff] = 0xFF;
		LedBuffer1[++bufOff] = 0xFF;
		LedBuffer1[++bufOff] = 0xFF;
		LedBuffer1[++bufOff] = 0xFF;
	}
	void send() {
		if(BufferSize>0) {
			ESP_LOGI(APA102c::LOG,"sending %d leds r[0]:%d, g[0]:%d, b[0]:%d, B[0]:%d\n", (BufferSize/4)-8,
				LedBuffer1[3], LedBuffer1[2], LedBuffer1[1], LedBuffer1[0]);
			ESP_LOG_BUFFER_HEX(APA102c::LOG, LedBuffer1, BufferSize);
			SPIInterface->send((uint8_t*)LedBuffer1,BufferSize);
		}
	}
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
void app_main() {
	esp_err_t ret;
	
	spi_device_handle_t spi;
	spi_bus_config_t buscfg;
	memset(&buscfg,0,sizeof(buscfg));
	buscfg.miso_io_num=PIN_NUM_MISO;
        buscfg.mosi_io_num=PIN_NUM_MOSI;
        buscfg.sclk_io_num=PIN_NUM_CLK;
        buscfg.quadwp_io_num=-1;
        buscfg.quadhd_io_num=-1;
	buscfg.max_transfer_sz=PARALLEL_LINES*320*2+8;

   spi_device_interface_config_t devcfg;
	memset(&devcfg,0,sizeof(devcfg));
#ifdef CONFIG_LCD_OVERCLOCK
        .clock_speed_hz=26*1000*1000,           //Clock out at 26 MHz
#else
        devcfg.clock_speed_hz=10*1000*1000,           //Clock out at 10 MHz
#endif
        devcfg.mode=0,                                //SPI mode 0
        devcfg.spics_io_num=PIN_NUM_CS,               //CS pin
        devcfg.queue_size=7,                          //We want to be able to queue 7 transactions at a time
        devcfg.pre_cb=lcd_spi_pre_transfer_callback,  //Specify pre-transfer callback to handle D/C line

	//Initialize the SPI bus
	ret=spi_bus_initialize(HSPI_HOST, &buscfg, 1);
	ESP_ERROR_CHECK(ret);
	//Attach the LCD to the SPI bus
	ret=spi_bus_add_device(HSPI_HOST, &devcfg, &spi);
	ESP_ERROR_CHECK(ret);
	//Initialize the LCD
	lcd_init(spi);
	
	//Policy,
	const int NUM_LEDS = 4;
	ESP32SPIWiring espSPI = ESP32SPIWiring::create(VSPI_HOST,LED_PIN_NONE,LED_PIN_MOSI,
																	LED_PIN_CLK,LED_PIN_NONE, 1024, 2);
	espSPI.init();
	APA102c apa102c(&espSPI);
	RGB ledBuf[NUM_LEDS] = {RGB::BLUE};
	for(int i=0;i<NUM_LEDS;i++) {
		ledBuf[i] = RGB::BLUE;
	}
	apa102c.init(NUM_LEDS,&ledBuf[0]);
	apa102c.send();
	vTaskDelay(2000 / portTICK_PERIOD_MS);
	for(int i=0;i<NUM_LEDS;i++) {
		ledBuf[i] = RGB::GREEN;
	}
	apa102c.init(NUM_LEDS,&ledBuf[0]);
	apa102c.send();
	vTaskDelay(2000 / portTICK_PERIOD_MS);
	for(int kk=0;kk<101;kk+=5) {
		for(int i=0;i<NUM_LEDS;i++) {
			ledBuf[i].setBrightness(kk);
		}
		apa102c.init(NUM_LEDS,&ledBuf[0]);
		apa102c.send();
		vTaskDelay(300 / portTICK_PERIOD_MS);
	}
	
	//Initialize the effect displayed
	ret=pretty_effect_init();
	ESP_ERROR_CHECK(ret);

	//Go do nice stuff.
	display_pretty_colors(spi);
}
#endif

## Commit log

2019-02-12 setting up initial project for wifi leds
2019-02-27 working leds
2019-03-23 adding hardware files
    [wifi-leds.brd, wifi-leds.sch]
2019-03-23 updated ignore, minor trace moves
    [wifi-leds.brd]
2019-03-23 added logo
    [wifi-leds.brd, wifi-leds.sch]
2019-03-30 shrunk foot print to fit on to a smaller fr4 board I have
    [wifi-leds.brd, wifi-leds.sch]
2019-09-02 redesign of the wifi LED board
    [wifi-leds2.brd, wifi-leds2.sch]
2019-10-19 updated gnd
    [wifi-leds2.brd]
